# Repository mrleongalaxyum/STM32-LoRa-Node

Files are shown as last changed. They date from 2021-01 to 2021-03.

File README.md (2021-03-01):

# Meteo_senzor
 Repo for PCB design

This is my custom hardware project created as a part of a college project at [Faculty of Electrical Engineering and Computing in Zagreb ](https://www.fer.unizg.hr/en "FER").

The board is based on [STM32L072/L073](https://www.st.com/en/microcontrollers-microprocessors/stm32l073rz.html) and features a [Bosch BME280](https://www.bosch-sensortec.com/products/environmental-sensors/humidity-sensors-bme280/) Temp/Pressure/humidity sensor. The LoRaWAN module is an [SX1276 by RadioControlli](https://www.radiocontrolli.com/rc-sm1276-868). The headers have all the GPIO exposed, except for the SPI1 which is occupied by the LoRa module. Headers are breadboard-friendly and leave 1 row of free breadboard pins at each side of the board. It can be easily flashed using an ST-Link dongle or a JLink which can be connected either to the P2 SWD header or the GPIO header. The battery is internally connected to an LDO and the battery voltage is supplied to the ADC_0 through a simple resistor voltage divider.

The PCB is drawn in Altium Designer and all the files are available in the repo.

Adafruit feather-style pinout graphics were made by using the template provided [here](https://youtu.be/ndVs1UvK6AE)

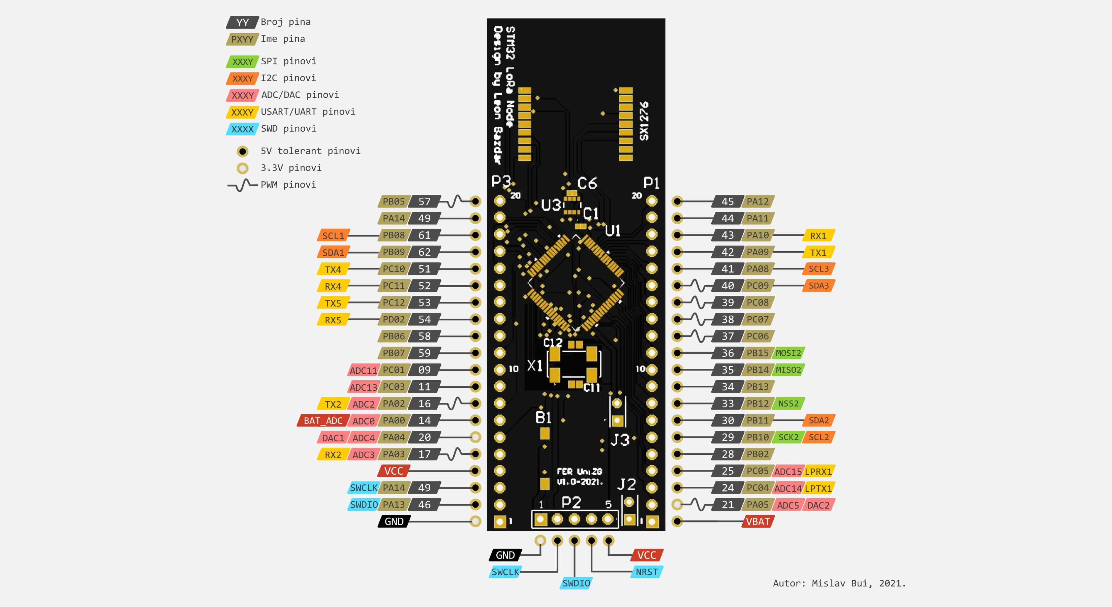
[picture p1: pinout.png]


The schematics can be found [here](https://github.com/mrleongalaxyum/STM32-LoRa-Node/blob/master/Schematic.pdf).

Example code for running on the board can be found [here](https://github.com/mrleongalaxyum/STM32L0-LoRaWAN-sensor).

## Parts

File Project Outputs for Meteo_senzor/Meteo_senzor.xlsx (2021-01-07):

Comment | Description | Designator | Footprint | LibRef | Quantity | Part Number | PartNumber | Case Code (Imperial) | Package / Case | Datasheet URL
PushButton 3x6x2.5 SMD |  | B1 | PushButton 3x6x2.5 SMD-Footprint-1 | CMP-011-00013-4 | 1
100nF |  | C1, C6, C7 | CAPC1005X56X25LL10T15 | CMP-2008-02842-1 | 3 | 0402YD104KAT2A
1uF |  | C2, C4, C5, C8 | CAPC2013X145X50LL20T25 | CMP-2007-01016-1 | 4 | C0805C105K4PACTU
10uF | Multilayer Ceramic Chip Capacitor, 10 uF, +/- 10%, 10 V, -55 to 125 degC, 0805 (2012 Metric), RoHS, Tape and Reel | C3, C9 | CAPC2013X145X20ML20 | CMP-2000-05452-1 | 2 |  |  |  | 0805(2012Metric) | http://download.siliconexpert.com/pdfs/2015/4/21/15/54/45/779/tdk_/manual/37024850441143360mlcc_commercial_general_en.pdf
100nF | Chip Capacitor, 0.1 uF, +/- 10%, 50 V, -55 to 125 degC, 0603 (1608 Metric), RoHS, Tape and Reel | C10 | CAPC1608X90X20LL10 | CMP-2000-07546-1 | 1 |  |  | 0603 |  | https://product.tdk.com/info/en/catalog/datasheets/mlcc_automotive_general_en.pdf
4.3pF |  | C11, C12 | CAPC1608X90X35LL10T15 | CMP-2006-02448-1 | 2 | GQM1885C2A4R3BB01D
1nF |  | C13 | CAPC1005X55X25LL05T05 | CMP-2008-01229-1 | 1 | VJ0402Y102KXXCW1BC
BAT current | Male Header, Pitch 2.54 mm, 1 x 2 Position, Height 8.21 mm, Tail Length 3.05 mm, -65 to 105 degC, RoHS, Bulk | J2 | TECO-5-146280-2_V | CMP-2000-07492-1 | 1 |  |  |  |  | http://www.te.com/commerce/DocumentDelivery/DDEController?Action=showdoc
DEV CUR | Male Header, Pitch 2.54 mm, 1 x 2 Position, Height 8.21 mm, Tail Length 3.05 mm, -65 to 105 degC, RoHS, Bulk | J3 | TECO-5-146280-2_V | CMP-2000-07492-1 | 1 |  |  |  |  | http://www.te.com/commerce/DocumentDelivery/DDEController?Action=showdoc
RC-SM1276-868 | https://www.radiocontrolli.com/it/componente/97/rc-sm1276-868 | LoRa | RC-SM1276-868 | CMP-021-00007-1 | 1
20p header | THT Vertical Pin Header WR-PHD, Pitch 2.54 mm, Single Row, 20 pins | P1, P3 | 61302011121 | CMP-1502-01102-1 | 2 | 61302011121 |  |  |  | https://katalog.we-online.de/em/datasheet/6130xx11121.pdf
SWD header 2.54 | THT Vertical Pin Header WR-PHD, Pitch 2.54 mm, Single Row, 5 pins | P2 | 61300511121 | CMP-1502-01068-1 | 1 | 61300511121 |  |  |  | https://katalog.we-online.de/em/datasheet/6130xx11121.pdf
100K | Chip Resistor, 100 KOhm, +/- 1%, 0.63 W, -55 to 155 degC, 0402 (1005 Metric), RoHS, Tape and Reel | R3 | RESC1005X40X25ML05T05 | CMP-2002-08123-2 | 1 |  |  | 0402
4.7k | Chip Resistor, 4.7 KOhm, +/- 1%, 0.1 W, -55 to 155 degC, 0402 (1005 Metric), RoHS, Tape and Reel | R4, R5 | RESC1005X40X25LL05T05 | CMP-1665-00031-3 | 2 |  | ERJ-2RKF4701X | 0402
0R |  | R6 | RESC1005X40X25ML05T10 | CMP-2002-08060-1 | 1 | RC0402JR-130RL
1.2MΩ | RES Thick Film, 1.2MΩ, 1%, 0.1W, 100ppm/°C, 0603 | R8 | FP-CRCW0603-e3-IPC_A | CMP-2000-03023-2 | 1 |  |  | 0603
3.24MΩ | RES Thick Film, 3.24MΩ, 1%, 0.1W, 100ppm/°C, 0603 | R9 | FP-CRCW0603-e3-MFG | CMP-2000-03317-2 | 1 |  |  | 0603
STM32L072RZT6 | No Description Available | U1 | LQFP64-10x10mm | STM32L072RZT6 | 1
MCP1700T-3302E/TT | Low Quiescent Current LDO, 3-Pin SOT-23, Extended Temperature, Tape and Reel | U2 | SOT-23-TT3_N | CMP-0136-00791-1 | 1
BME280 | SENSOR PRESSURE HUMIDITY TEMP | U3 | FP-BME280-MFG | CMP-191074-000001-1 | 1
ABS25-32.768KHZ-6-T | Low Frequency Crystal, 32.768 KHz, 6 pF, +/- 20 ppm, -40 to 85 degC, 4-Pin SMD, RoHS, Tape and Reel | X1 | ABRA-ABS25-4_V | CMP-2000-05036-1 | 1 |  |  |  | 8mmx3.8mm | https://datasheet.ciiva.com/854/abs25-854528.pdf

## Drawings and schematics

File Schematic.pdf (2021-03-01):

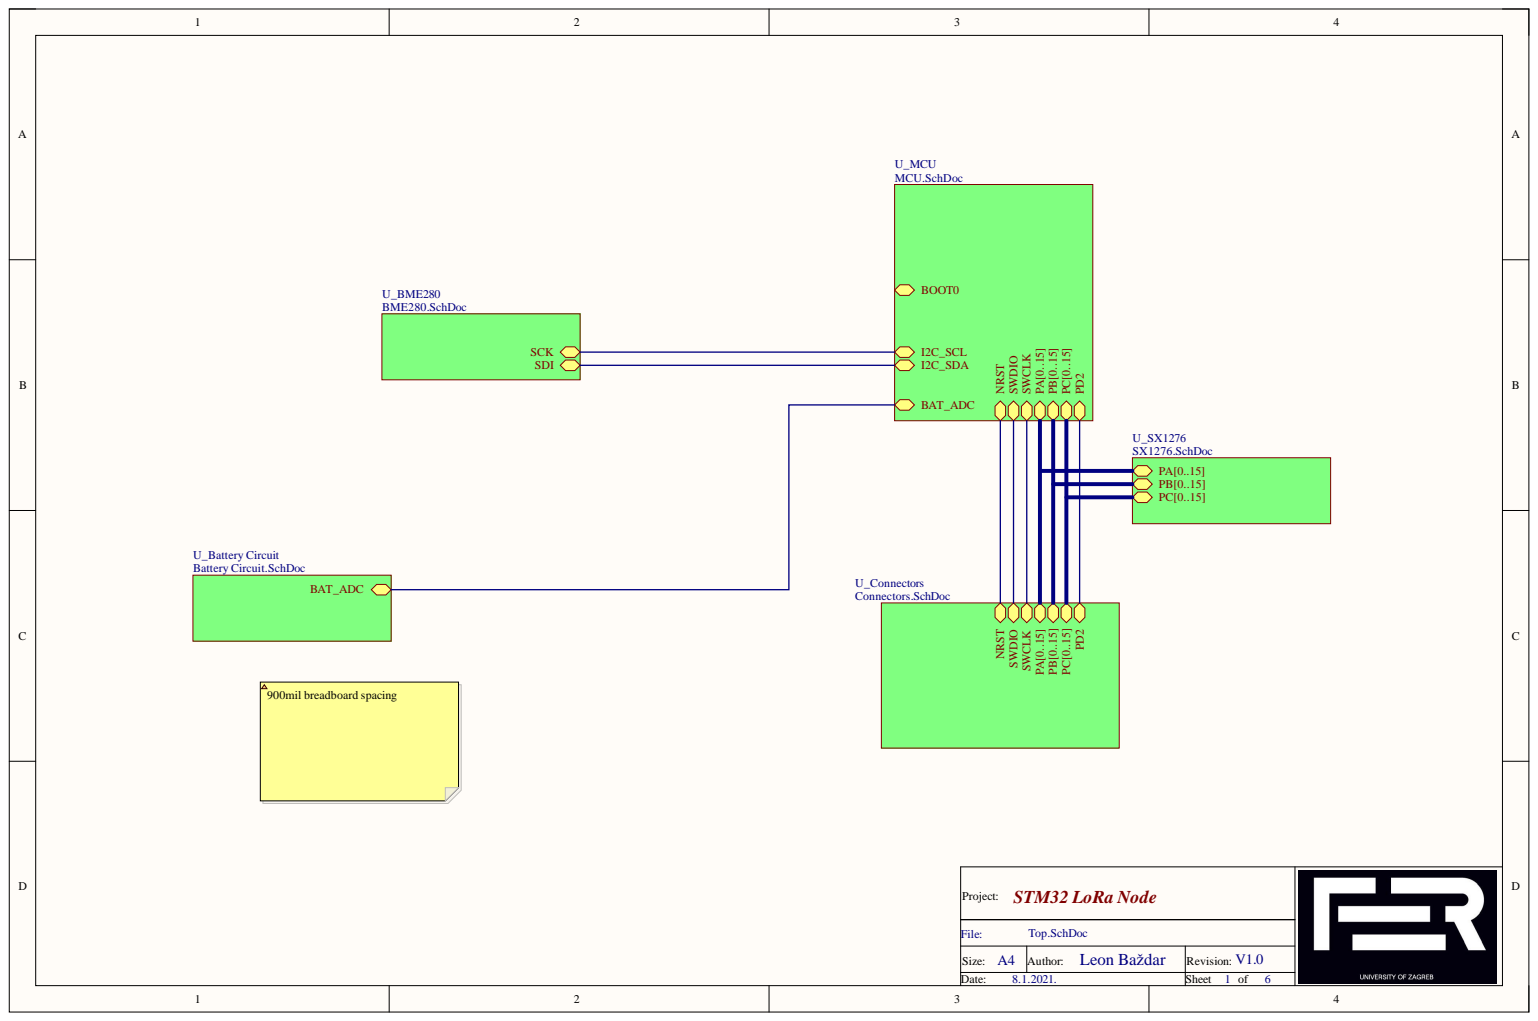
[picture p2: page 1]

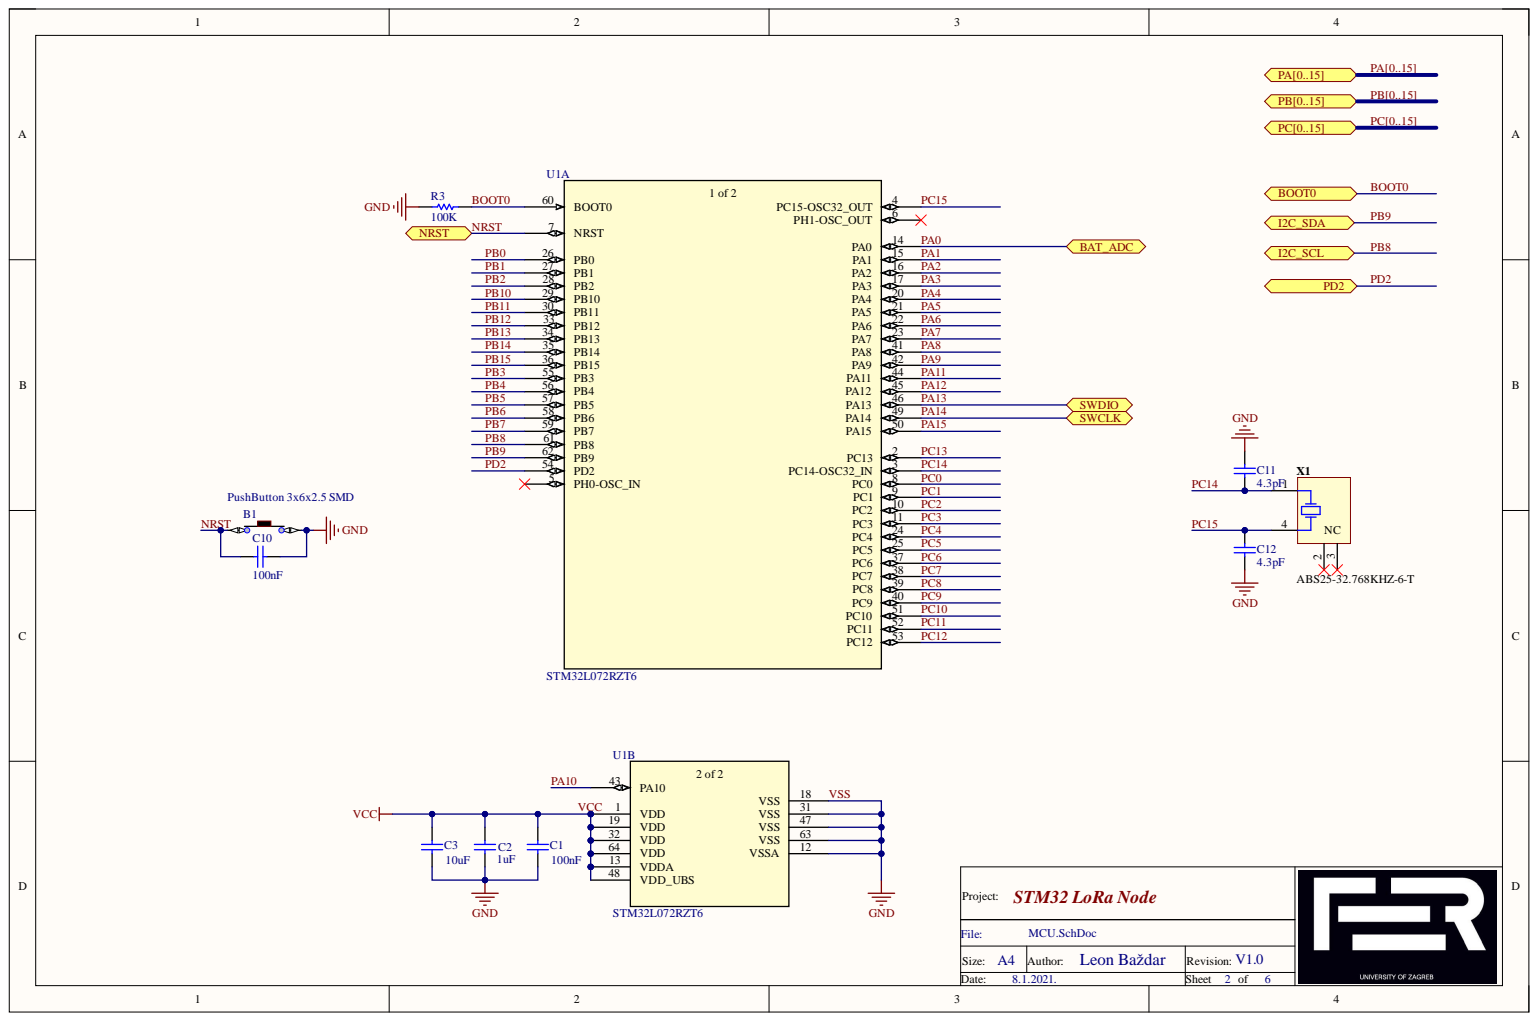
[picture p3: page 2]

1 9 | 4 7
3 2 | 6 3
6 4 | 1 2

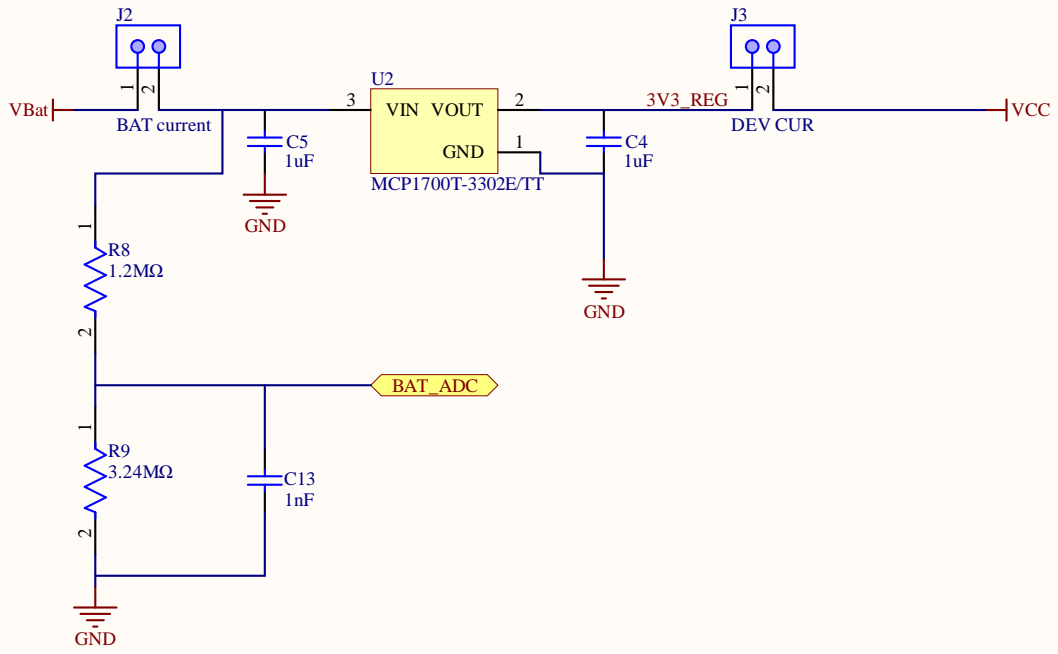
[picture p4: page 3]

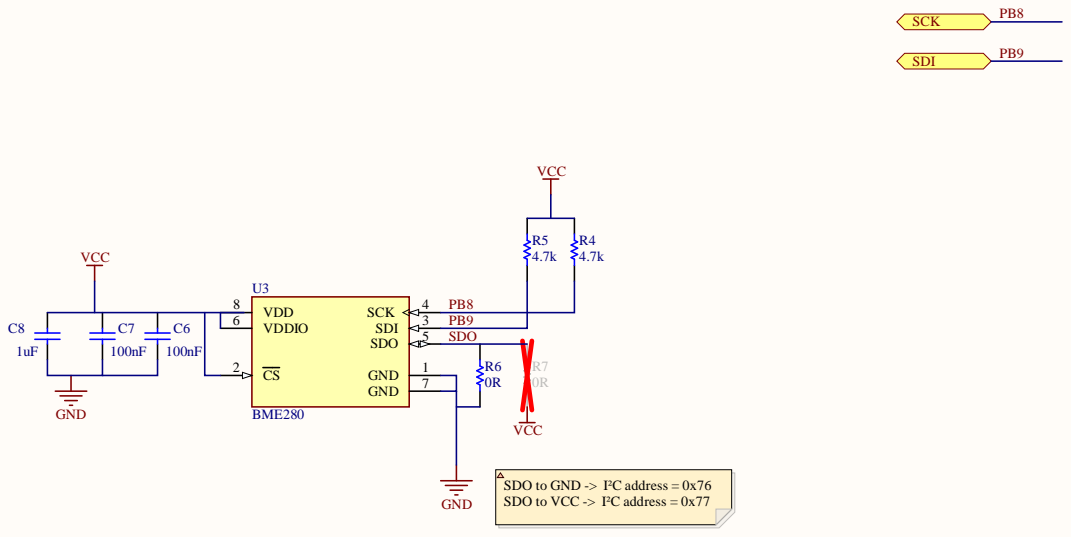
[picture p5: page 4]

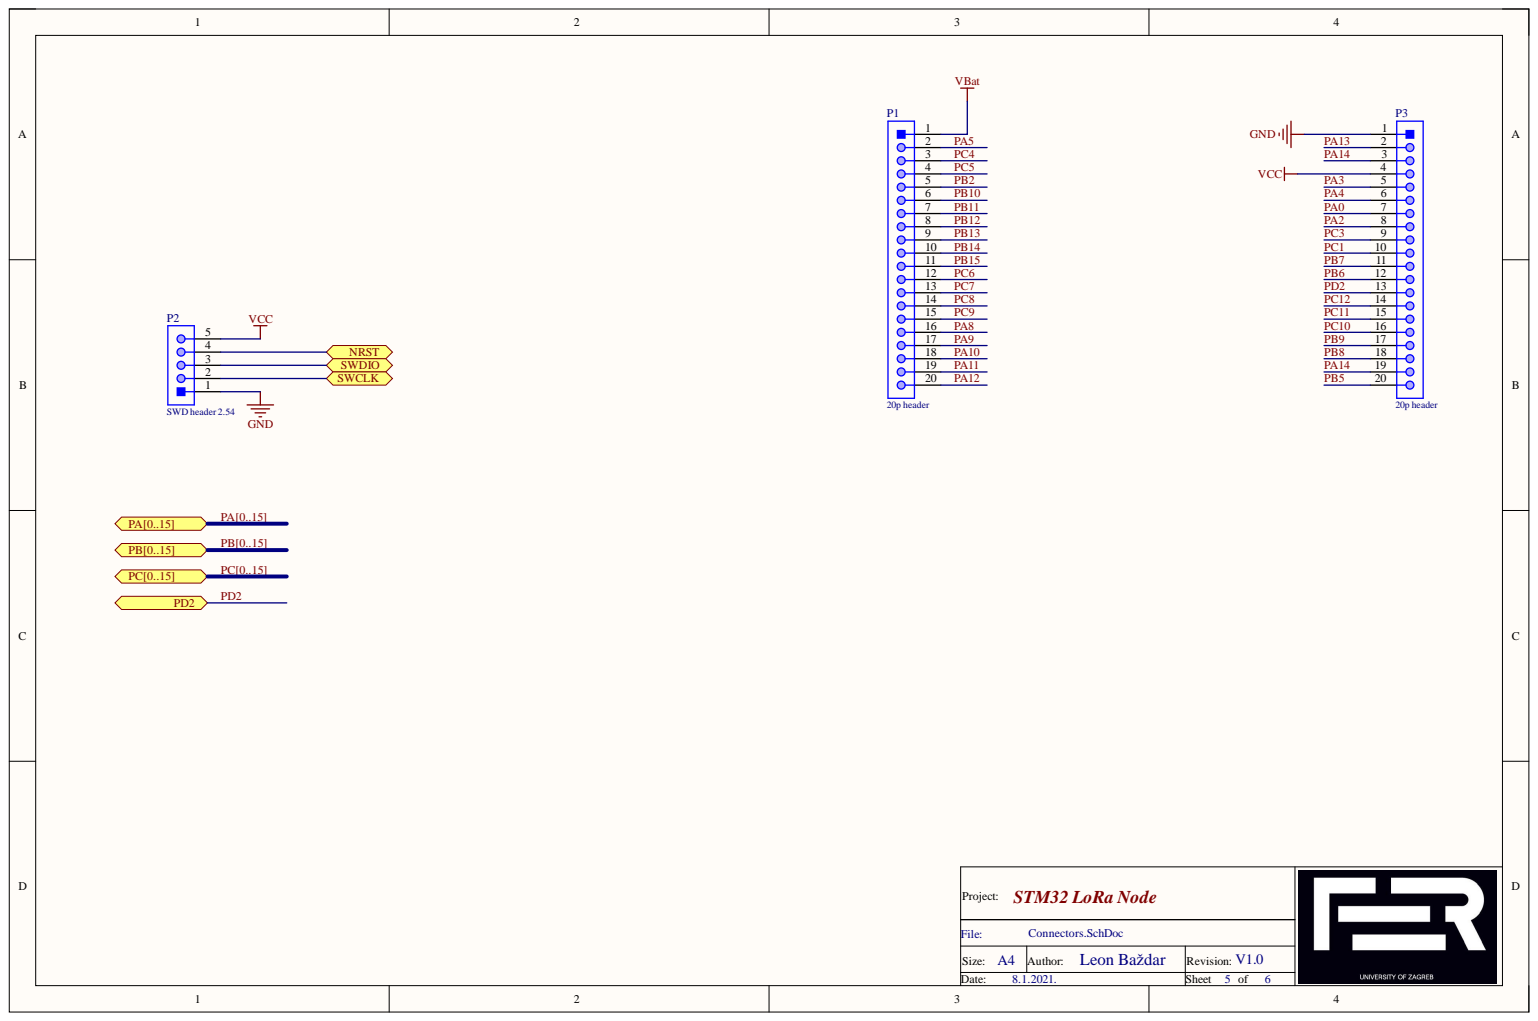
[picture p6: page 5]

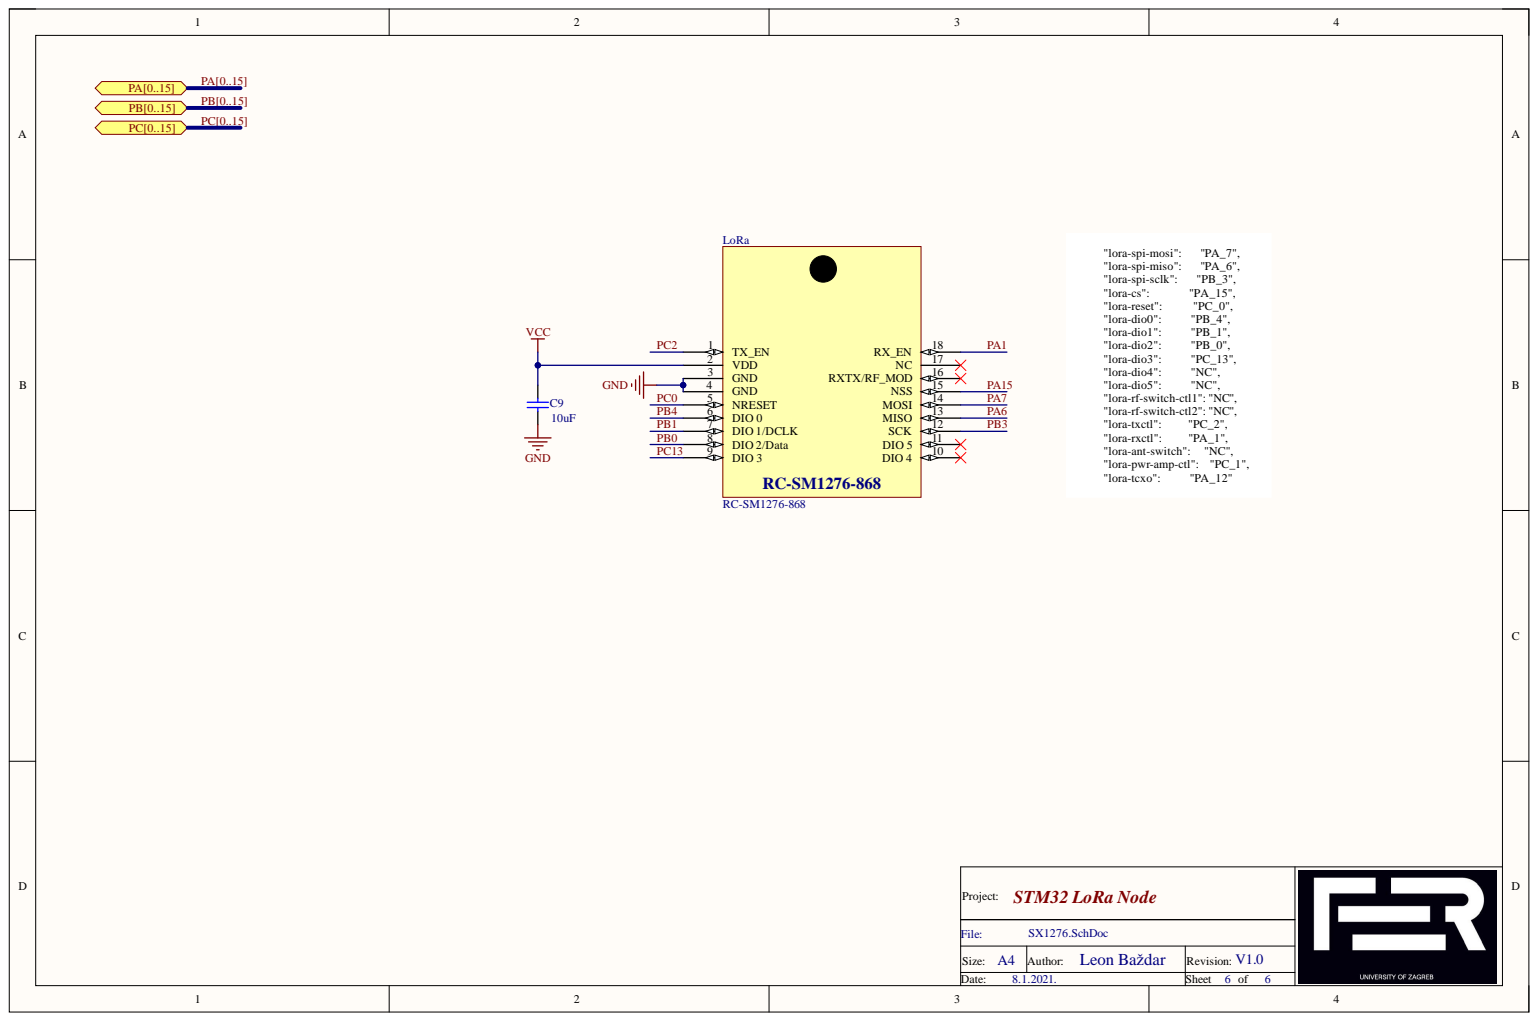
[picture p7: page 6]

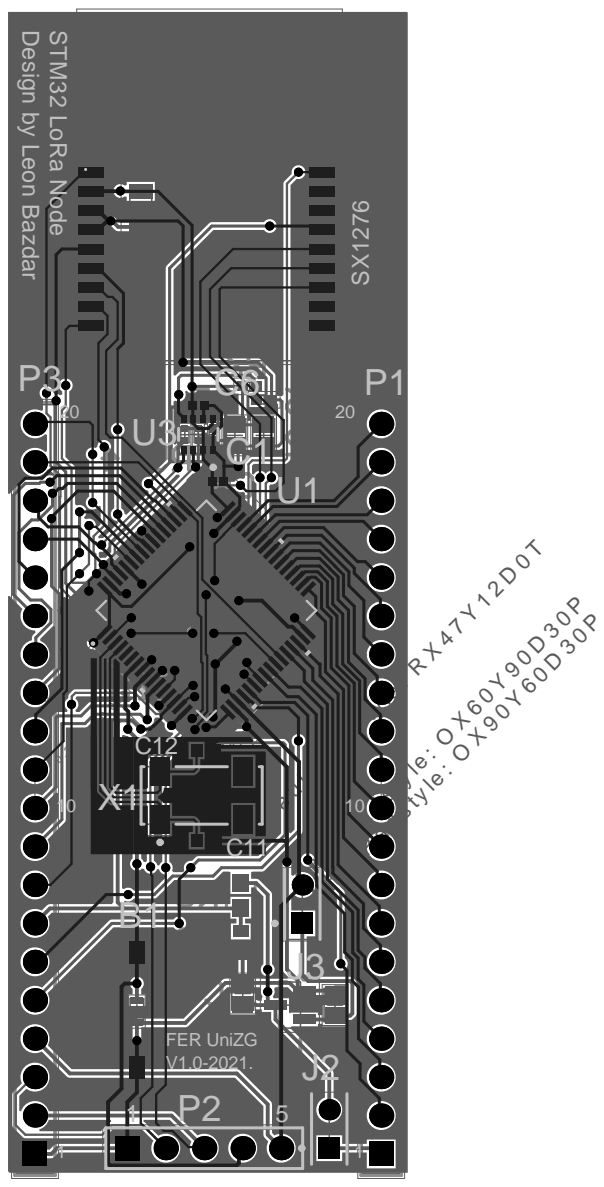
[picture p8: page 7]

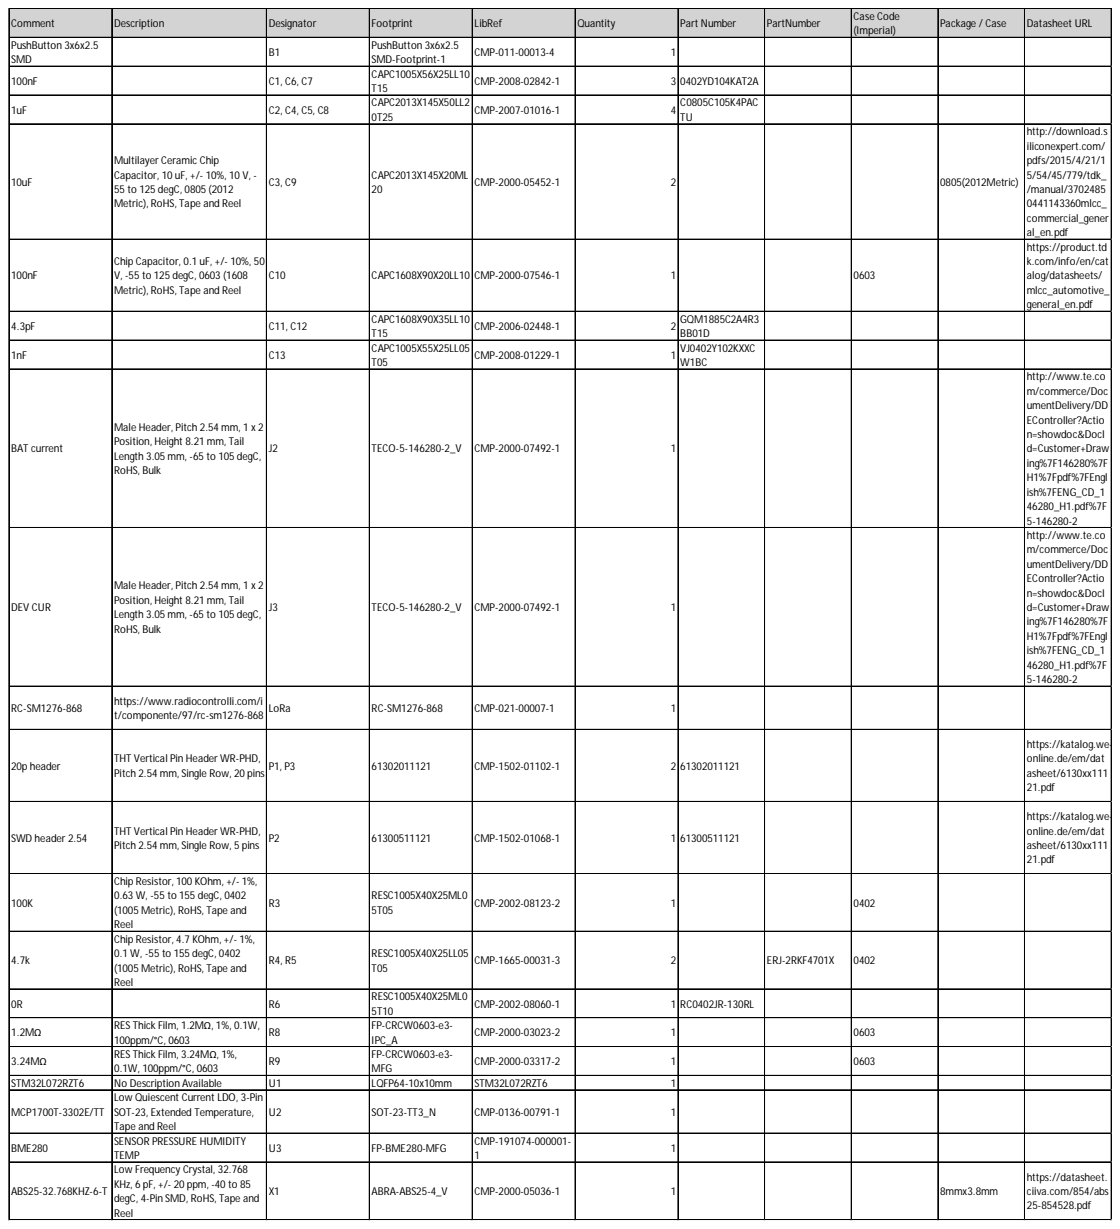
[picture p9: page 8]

Comment | Description | Designator | Footprint | LibRef | Quantity | Part Number | PartNumber | Case Code (Imperial) | Package / Case | Datasheet URL

PushButton 3x6x2.5 SMD | | B1 | PushButton 3x6x2.5 SMD-Footprint-1 | CMP-011-00013-4 | 1

100nF | | C1, C6, C7 | CAPC1005X56X25LL10 T15 | CMP-2008-02842-1 | 3 0402YD104KAT2A

1uF | | C2, C4, C5, C8 | CAPC2013X145X50LL2 0T25 | CMP-2007-01016-1 | 4 C0805C105K4PAC | TU

10uF | Multilayer Ceramic Chip Capacitor, 10 uF, +/- 10%, 10 V, -55 to 125 degC, 0805 (2012 Metric), RoHS, Tape and Reel | C3, C9 | CAPC2013X145X20ML 20 | CMP-2000-05452-1 | 2 | | | | 0805(2012Metric) | http://download.siliconexpert.com/pdfs/2015/4/21/15/54/45/779/tdk_/manual/37024850441143360mlcc_commercial_general_en.pdf

100nF | Chip Capacitor, 0.1 uF, +/- 10%, 50 V, -55 to 125 degC, 0603 (1608 Metric), RoHS, Tape and Reel | C10 | CAPC1608X90X20LL10 CMP-2000-07546-1 | | 1 | | | 0603 | | https://product.tdk.com/info/en/catalog/datasheets/mlcc_automotive_general_en.pdf

4.3pF | | C11, C12 | CAPC1608X90X35LL10 T15 | CMP-2006-02448-1 | 2 GQM1885C2A4R3 | BB01D

1nF | | C13 | CAPC1005X55X25LL05 T05 | CMP-2008-01229-1 | 1 | VJ0402Y102KXXC W1BC

BAT current | Male Header, Pitch 2.54 mm, 1 x 2 Position, Height 8.21 mm, Tail Length 3.05 mm, -65 to 105 degC, RoHS, Bulk | J2 | TECO-5-146280-2_V | CMP-2000-07492-1 | 1 | | | | | http://www.te.com/commerce/DocumentDelivery/DDEController?Action=showdoc&DocId=Customer+Draw ing%7F146280%7F H1%7Fpdf%7FEngl ish%7FENG_CD_1 46280_H1.pdf%7F 5-146280-2

DEV CUR | Male Header, Pitch 2.54 mm, 1 x 2 Position, Height 8.21 mm, Tail Length 3.05 mm, -65 to 105 degC, RoHS, Bulk | J3 | TECO-5-146280-2_V | CMP-2000-07492-1 | 1 | | | | | http://www.te.com/commerce/DocumentDelivery/DDEController?Action=showdoc&DocId=Customer+Draw ing%7F146280%7F H1%7Fpdf%7FEngl ish%7FENG_CD_1 46280_H1.pdf%7F 5-146280-2

RC-SM1276-868 | https://www.radiocontrolli.com/it/componente/97/rc-sm1276-868 | LoRa | RC-SM1276-868 | CMP-021-00007-1 | 1

20p header | THT Vertical Pin Header WR-PHD, Pitch 2.54 mm, Single Row, 20 pins P1, P3 | | 61302011121 | CMP-1502-01102-1 | 2 61302011121 | | | | | https://katalog.we-online.de/em/datasheet/6130xx111 21.pdf

SWD header 2.54 | THT Vertical Pin Header WR-PHD, Pitch 2.54 mm, Single Row, 5 pins | P2 | 61300511121 | CMP-1502-01068-1 | 1 | 61300511121 | | | | https://katalog.we-online.de/em/datasheet/6130xx111 21.pdf

100K | Chip Resistor, 100 KOhm, +/- 1%, 0.63 W, -55 to 155 degC, 0402 (1005 Metric), RoHS, Tape and Reel | R3 | RESC1005X40X25ML0 5T05 | CMP-2002-08123-2 | 1 | | | 0402

4.7k | Chip Resistor, 4.7 KOhm, +/- 1%, 0.1 W, -55 to 155 degC, 0402 (1005 Metric), RoHS, Tape and Reel | R4, R5 | RESC1005X40X25LL05 T05 | CMP-1665-00031-3 | 2 | | ERJ-2RKF4701X | 0402

0R | | R6 | RESC1005X40X25ML0 5T10 | CMP-2002-08060-1 | 1 | RC0402JR-130RL

1.2MΩ | RES Thick Film, 1.2MΩ, 1%, 0.1W, 100ppm/°C, 0603 | R8 | FP-CRCW0603-e3-IPC_A | CMP-2000-03023-2 | 1 | | | 0603

3.24MΩ | RES Thick Film, 3.24MΩ, 1%, 0.1W, 100ppm/°C, 0603 | R9 | FP-CRCW0603-e3-MFG | CMP-2000-03317-2 | 1 | | | 0603

STM32L072RZT6 | No Description Available | U1 | LQFP64-10x10mm | STM32L072RZT6 | 1
MCP1700T-3302E/TT | Low Quiescent Current LDO, 3-Pin SOT-23, Extended Temperature, Tape and Reel | U2 | SOT-23-TT3_N | CMP-0136-00791-1 | 1

BME280 | SENSOR PRESSURE HUMIDITY TEMP | U3 | FP-BME280-MFG | CMP-191074-000001-1 | 1

ABS25-32.768KHZ-6-T | Low Frequency Crystal, 32.768 KHz, 6 pF, +/- 20 ppm, -40 to 85 degC, 4-Pin SMD, RoHS, Tape and Reel | X1 | ABRA-ABS25-4_V | CMP-2000-05036-1 | 1 | | | | 8mmx3.8mm | https://datasheet.ciiva.com/854/abs 25-854528.pdf

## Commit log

2020-10-23 Add Bidirectional ports to MCU.sch
    [MCU.SchDoc]
2020-10-24 replaced MCU to L072RZT6, added ports, established hieararchy sch design
    [MCU.SchDoc, Meteo_senzor.PrjPcb, PCB1.PcbDoc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]
2020-10-24 Added net labels
    [MCU.SchDoc, Top.SchDoc]
2020-10-24 Updated hiearchy Added battery circuit
    [Battery Circuit.SchDoc, MCU.SchDoc, Meteo_senzor.PrjPcb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]
2020-10-24 Update template
    [Battery Circuit.SchDoc, MCU.SchDoc, Meteo_senzor.PrjPcb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]
2020-10-25 backup commit
    [MCU.SchDoc, Meteo_senzor.PrjPcb, Sensors.SchDoc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]
2020-10-25 add template file
    [Meteo_senzor.PrjPcb]
2020-10-27 add BME280 schematic
    [BME280.SchDoc, MCU.SchDoc, Meteo_senzor.PrjPcb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]
2020-10-27 Added Connectors.sch Added SWDIO & I2C header
    [BME280.SchDoc, Battery Circuit.SchDoc, Connectors.SchDoc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]
2020-10-27 Fix bus error on Top.sch
    [Top.SchDoc]
2020-10-28 Added SX1276.SchDoc
    [MCU.SchDoc, Meteo_senzor.PrjPcb, SX1276.SchDoc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]
2020-10-28 Added lora module part added pin headers Added i2c address variants
    [BME280.SchDoc, Connectors.SchDoc, MCU.SchDoc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]
2020-10-28 added pcb blank
    [Meteo_senzor.PrjPcb, PCB1.PcbDoc]
2020-10-28 initial PCB commit
    [PCB1.PcbDoc]
2020-10-28 Fixed annotation
    [BME280.SchDoc, Battery Circuit.SchDoc, Connectors.SchDoc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]
2020-10-31 edited PCB size, added rst button
    [Battery Circuit.SchDoc, Connectors.SchDoc, MCU.SchDoc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]
2020-11-02 Added LSE, needs to be routed
    [Connectors.SchDoc, MCU.SchDoc, Meteo_senzor.PrjPcb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]
2020-11-02 updated headers
    [Connectors.SchDoc, MCU.SchDoc, PCB1.PcbDoc]
2020-12-30 Changed PCB size, modified layout, major rehaul....
    [BME280.SchDoc, Connectors.SchDoc, MCU.SchDoc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]
2021-01-02 Added ADC parts for bat monitoring
    [Battery Circuit.SchDoc, MCU.SchDoc, PCB1.PcbDoc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]
2021-01-07 Routed some connections
    [Battery Circuit.SchDoc, Connectors.SchDoc, MCU.SchDoc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]
2021-01-07 Everything routed + copper pour on bottom layer
    [Connectors.SchDoc, MCU.SchDoc, PCB1.PcbDoc]
2021-01-07 Generated PDF
    [Meteo_senzor.PrjPcb, Meteo_senzor.xlsx, PCB1.PcbDoc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]
2021-03-01 Added board pinout
2021-03-01 Add Schematic.pdf
